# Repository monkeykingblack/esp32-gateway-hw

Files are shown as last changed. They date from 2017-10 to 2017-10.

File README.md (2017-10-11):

#ESP32-GATEWAY-HARDWARE

##Features

- ESP32 WIFI, Bluetooth LE, SoC - 240MHz - Module ESP32 Wrover
- Tracking location by GPS-NEO-6M IC
- Send SMS via sim card by 
- Automatic select 3 power sources (DC6-28V, USB and Battery)
- Charger battery lithium 3.7V
- 1 Power LED, 1 Status GPS LED, 1 Status GSM LED

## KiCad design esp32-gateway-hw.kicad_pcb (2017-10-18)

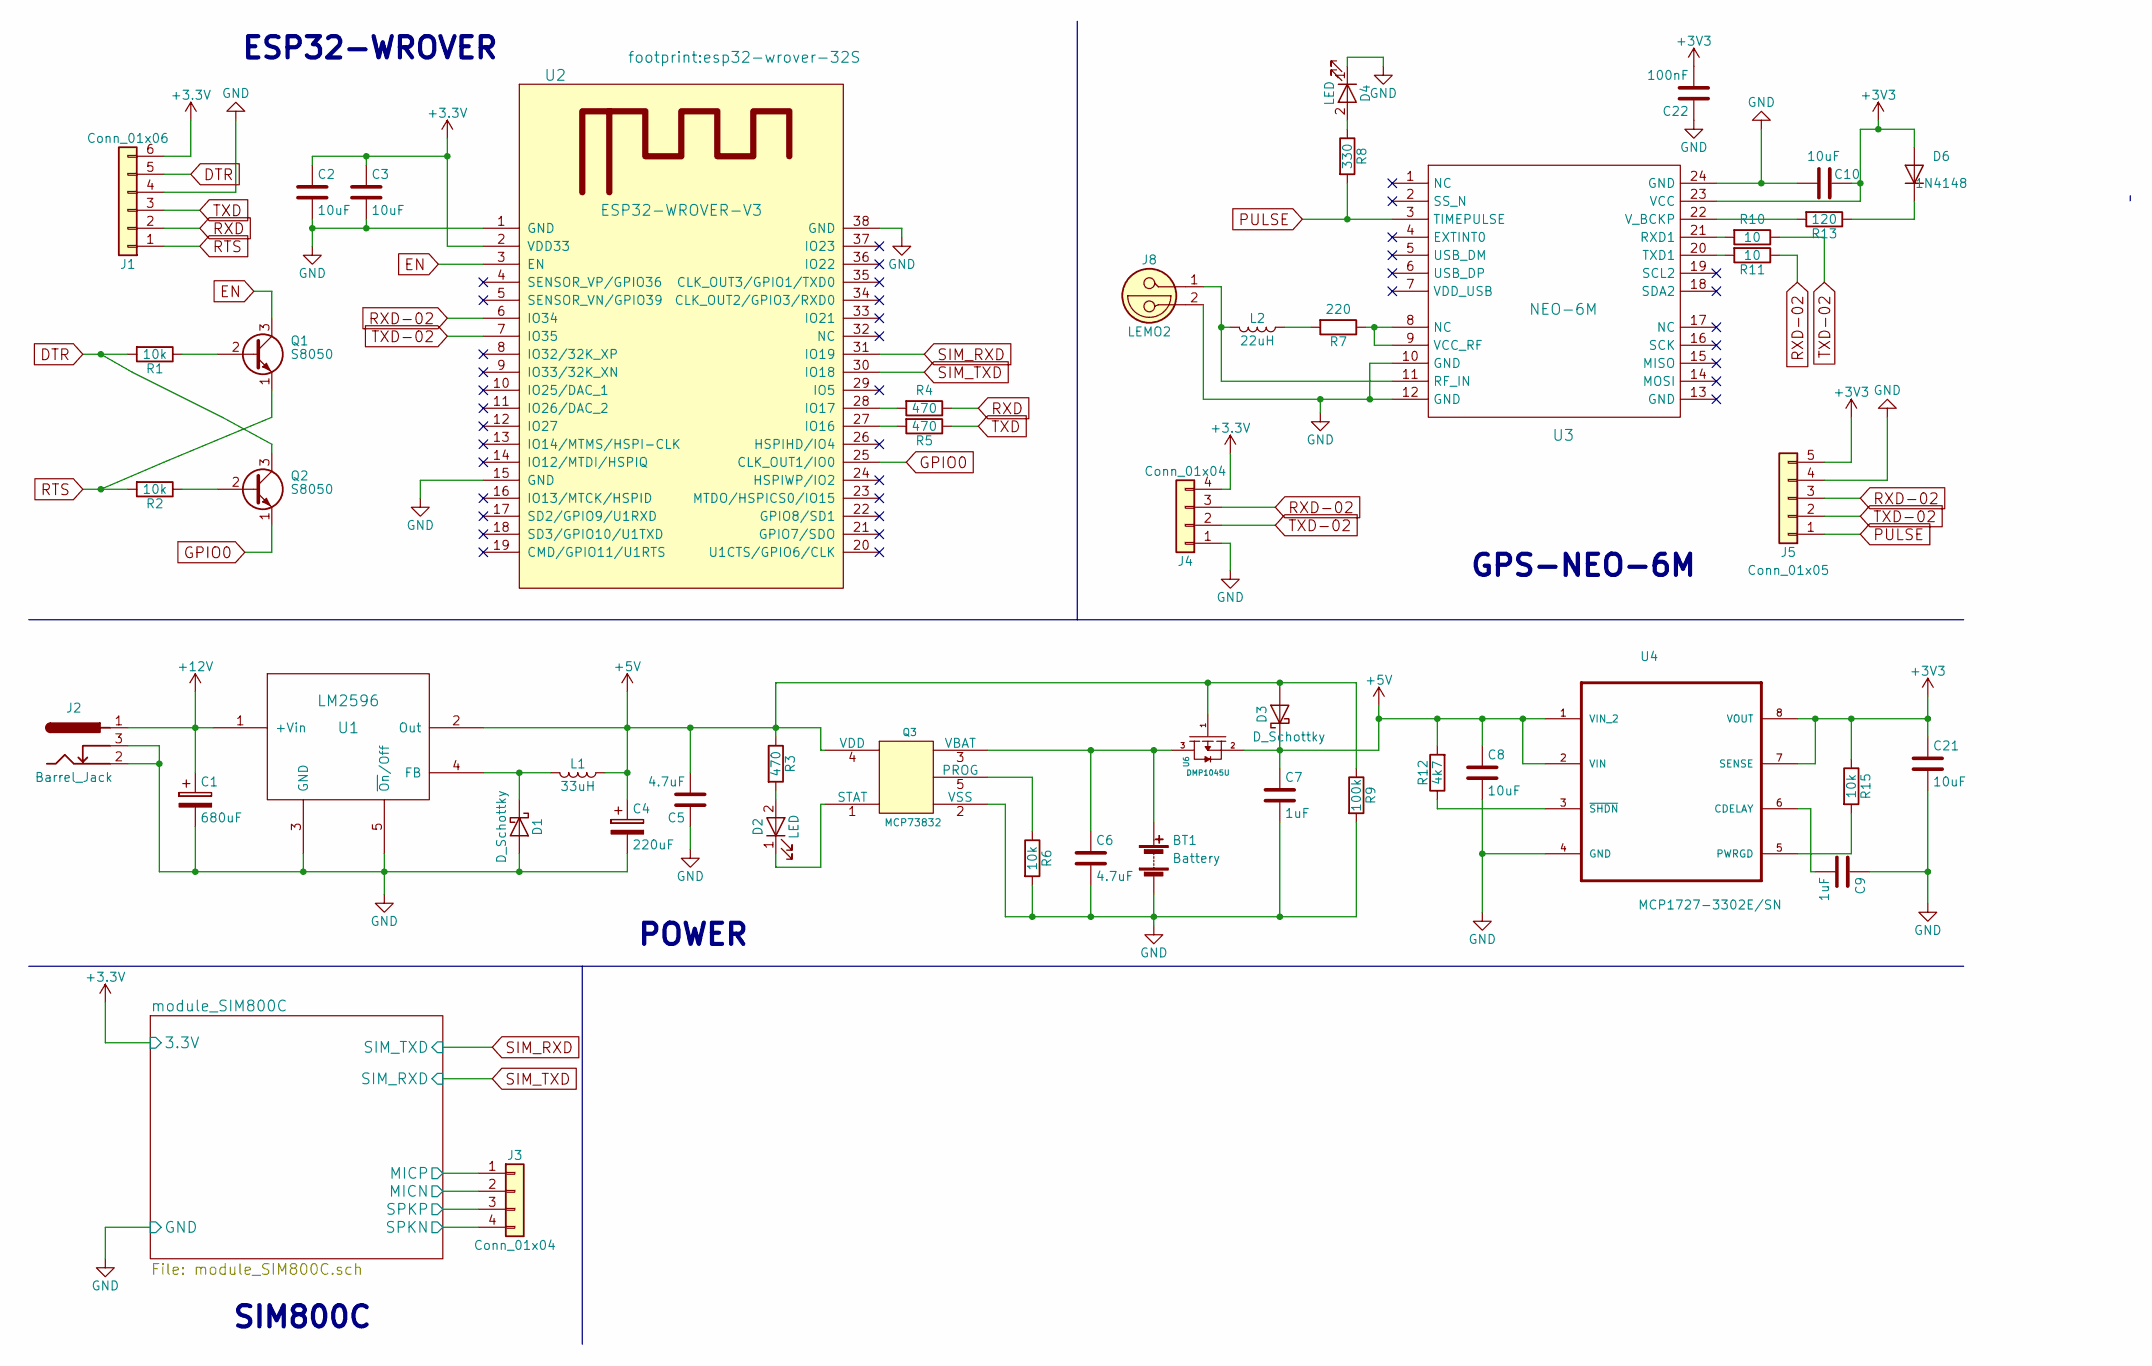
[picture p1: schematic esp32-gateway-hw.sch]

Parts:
BT1: Battery; JST_EH_B02B-EH-A_02x2.50mm_Straight
C1: 680uF; CP_Elec_4x5.3
C2, C3, C8, C10, C21: 10uF; C_0603
C4: 220uF; CP_Elec_4x5.3
C5, C6: 4.7uF; C_0603
C7, C9: 1uF; C_0603
C22: 100nF; C_0603
D1, D3: D_Schottky; D_SOD-123
D2, D4: LED; LED_D3.0mm
D6: 1N4148; D_SOD-123
J1: Conn_01x06; Socket_Strip_Straight_1x06_Pitch2.54mm
J2: Barrel_Jack; CUI-PJ-102A_dc-barrel-jack
J3, J4: Conn_01x04; Socket_Strip_Straight_1x04_Pitch2.54mm
J5: Conn_01x05; Socket_Strip_Straight_1x05_Pitch2.54mm
J8: LEMO2; SMA_Straight
L1: 33uH; INDUCTOR_SMD_DIP2
L2: 22uH; INDUCTOR_SMD_DIP2
Q1, Q2: S8050; SOT-23_standar
Q3: MCP73832; SOT-23-5_HandSoldering
R1, R2, R6, R15: 10k; R_0603
R3, R4, R5: 470; R_0603
R7: 220; R_0603
R8: 330; R_0603
R9: 100k; R_0603
R10, R11: 10; R_0603
R12: 4k7; R_0603
R13: 120; R_0603
U1: LM2596; TO-263-5_TabPin3
U2: ESP32-WROVER-V3; esp32-wrover-32S
U3: NEO-6M; GPS24P-SMD-1.1-16X12.2MM
U4: MCP1727-3302E/SN; SOIC-8_3.9x4.9mm_Pitch1.27mm; Digi-Key_Part_Number MCP1727-3302E/SN-ND
U6: DMP1045U; SOT-23

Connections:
+3V3: C2.1, C3.1, C10.1, C21.1, C22.2, D6.2 (A), J1.6, J4.4, J5.5, R15.1, U2.2 (VDD33), U3.23 (VCC), U4.7 (SENSE), U4.8 (VOUT); also elsewhere on the board
+5V: C4.1, C5.2, C7.1, C8.1, D3.1 (K), D3.2 (A), L1.1, Q3.4 (VDD), R3.1, R9.1, R12.2, U1.2 (Out), U4.1 (VIN_2), U4.2 (VIN), U6.1, U6.2
+12V: C1.1, J2.1, U1.1 (+Vin)
/module_SIM800C/MICN: J3.2; also elsewhere on the board
/module_SIM800C/MICP: J3.1; also elsewhere on the board
/module_SIM800C/SPKN: J3.4; also elsewhere on the board
/module_SIM800C/SPKP: J3.3; also elsewhere on the board
DTR: J1.5, Q2.3 (C), R1.2
EN: Q1.3 (C), U2.3 (EN)
GND: BT1.2 (-), C1.2, C2.2, C3.2, C4.2, C5.1, C6.2, C7.2, C8.2, C9.1, C10.2, C21.2, C22.1, D1.2 (A), D4.1 (K), J1.4, J2.2, J2.3, J4.1, J5.4, J8.2, Q3.2 (VSS), R6.2, R9.2, U1.3 (GND), U1.5 (~On~/Off), U2.1 (GND), U2.15 (GND), U2.38 (GND), U3.10 (GND), U3.12 (GND), U3.24 (GND), U4.4 (GND); also elsewhere on the board
GPIO0: Q2.1 (E), U2.25 (CLK_OUT1/IO0)
unnamed: BT1.1 (+), C6.1, Q3.3 (VBAT), U6.3
unnamed: C9.2, U4.6 (CDELAY)
unnamed: D1.1 (K), L1.2, U1.4 (FB)
unnamed: D2.1 (K), Q3.1 (STAT)
unnamed: D2.2 (A), R3.2
unnamed: D4.2 (A), R8.1
unnamed: D6.1 (K), R13.1
unnamed: J8.1, L2.2, U3.11 (RF_IN)
unnamed: L2.1, R7.2
unnamed: Q1.2 (B), R1.1
unnamed: Q2.2 (B), R2.1
unnamed: Q3.5 (PROG), R6.1
unnamed: R4.2, U2.28 (IO17)
unnamed: R5.2, U2.27 (IO16)
unnamed: R7.1, U3.8 (NC), U3.9 (VCC_RF)
unnamed: R10.2, U3.21 (RXD1)
unnamed: R11.2, U3.20 (TXD1)
unnamed: R12.1, U4.3 (~SHDN)
unnamed: R13.2, U3.22 (V_BCKP)
unnamed: R15.2, U4.5 (PWRGD)
PULSE: J5.1, R8.2, U3.3 (TIMEPULSE)
RTS: J1.1, Q1.1 (E), R2.2
RXD: J1.2, R4.1
RXD-02: J4.3, J5.3, R11.1, U2.6 (IO34)
SIM_RXD: U2.31 (IO19); also elsewhere on the board
SIM_TXD: U2.30 (IO18); also elsewhere on the board
TXD: J1.3, R5.1
TXD-02: J4.2, J5.2, R10.1, U2.7 (IO35)

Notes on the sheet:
ESP32-WROVER
GPS-NEO-6M
POWER
SIM800C

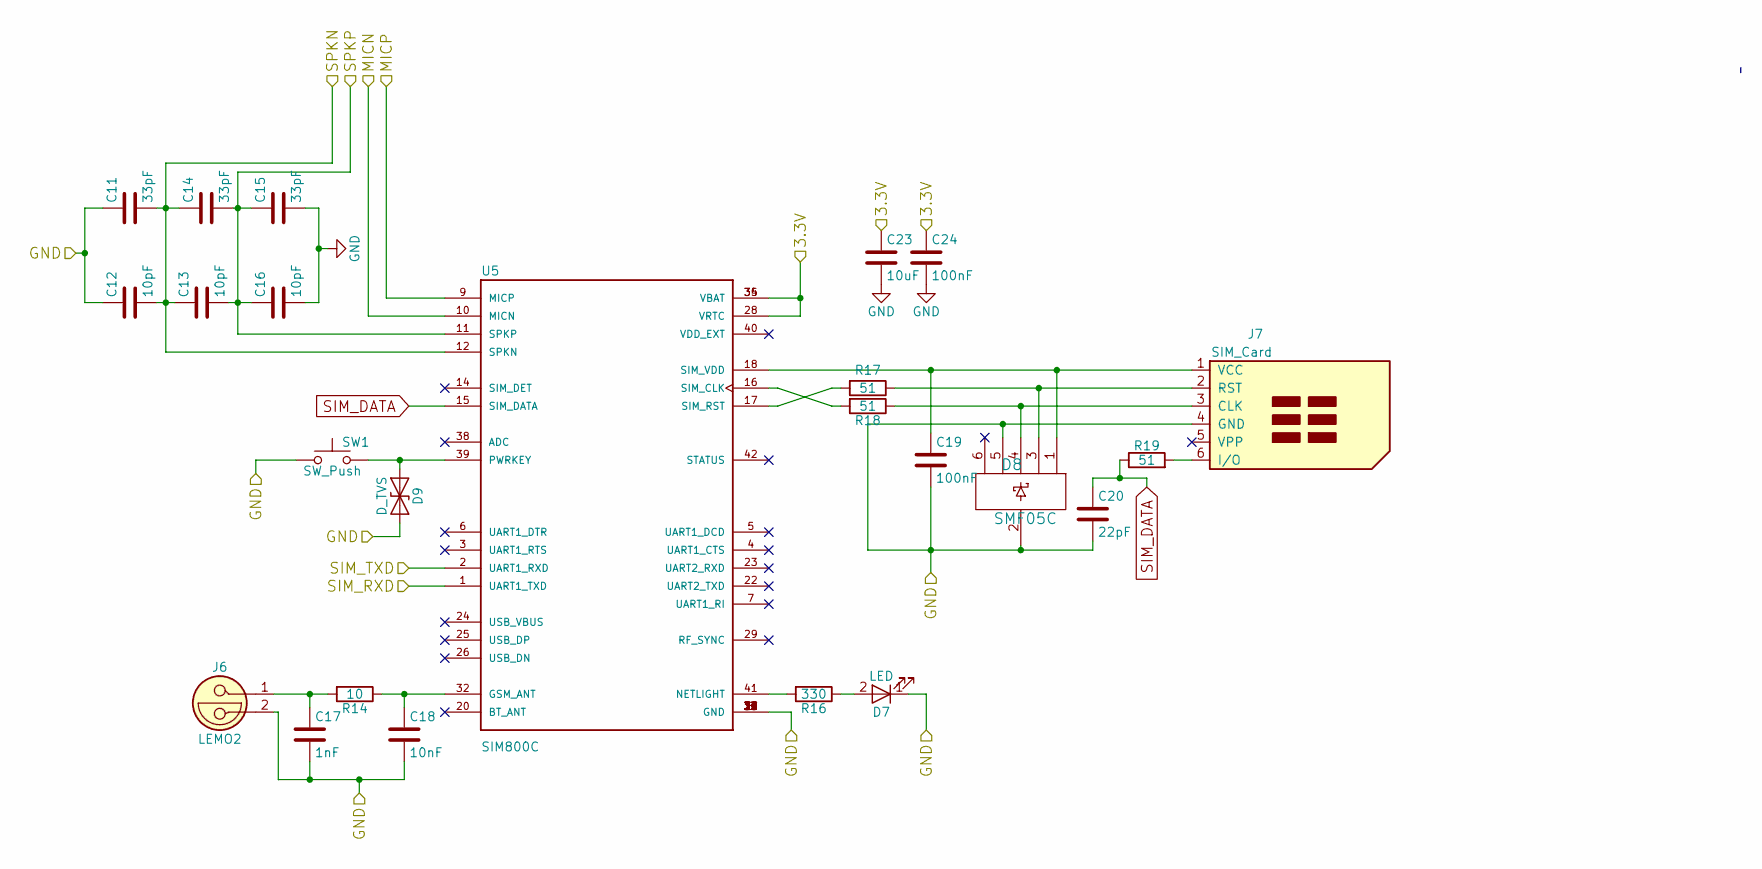
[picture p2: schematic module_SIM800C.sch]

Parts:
C11, C14, C15: 33pF; C_0603
C12, C13, C16: 10pF; C_0603
C17: 1nF; C_0603
C18: 10nF; C_0603
C19, C24: 100nF; C_0603
C20: 22pF; C_0603
C23: 10uF; C_0603
D7: LED; LED_D3.0mm
D8: SMF05C; SC70-6L
D9: D_TVS; DO-214AC(SMA)
J6: LEMO2; SMA_Straight
J7: SIM_Card; MOLEX_47553-2001_SIMCARD
R14: 10; R_0603
R16: 330; R_0603
R17, R18, R19: 51; R_0603
SW1: SW_Push; SW_PUSH_6mm_h4.3mm
U5: SIM800C; sim800C

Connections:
+3V3: C23.1, C24.1, U5.28 (VRTC), U5.34 (VBAT), U5.35 (VBAT); also elsewhere on the board
/module_SIM800C/MICN: U5.10 (MICN); also elsewhere on the board
/module_SIM800C/MICP: U5.9 (MICP); also elsewhere on the board
/module_SIM800C/SPKN: C11.2, C12.2, C13.1, C14.1, U5.12 (SPKN); also elsewhere on the board
/module_SIM800C/SPKP: C13.2, C14.2, C15.1, C16.1, U5.11 (SPKP); also elsewhere on the board
GND: C11.1, C12.1, C15.2, C16.2, C17.2, C18.2, C19.2, C20.2, C23.2, C24.2, D7.1 (K), D8.2, D8.5, D9.2 (A2), J6.2, J7.4 (GND), SW1.1, U5.8 (GND), U5.13 (GND), U5.19 (GND), U5.21 (GND), U5.27 (GND), U5.30 (GND), U5.31 (GND), U5.33 (GND), U5.36 (GND), U5.37 (GND); also elsewhere on the board
unnamed: C17.1, J6.1, R14.2
unnamed: C18.1, R14.1, U5.32 (GSM_ANT)
unnamed: C19.1, D8.1, J7.1 (VCC), U5.18 (SIM_VDD)
unnamed: D7.2 (A), R16.1
unnamed: D8.3, J7.2 (RST), R17.1
unnamed: D8.4, J7.3 (CLK), R18.1
unnamed: D9.1 (A1), SW1.2, U5.39 (PWRKEY)
unnamed: J7.6 (I/O), R19.2
unnamed: R16.2, U5.41 (NETLIGHT)
unnamed: R17.2, U5.17 (SIM_RST)
unnamed: R18.2, U5.16 (SIM_CLK)
SIM_DATA: C20.1, R19.1, U5.15 (SIM_DATA)
SIM_RXD: U5.2 (UART1_RXD); also elsewhere on the board
SIM_TXD: U5.1 (UART1_TXD); also elsewhere on the board

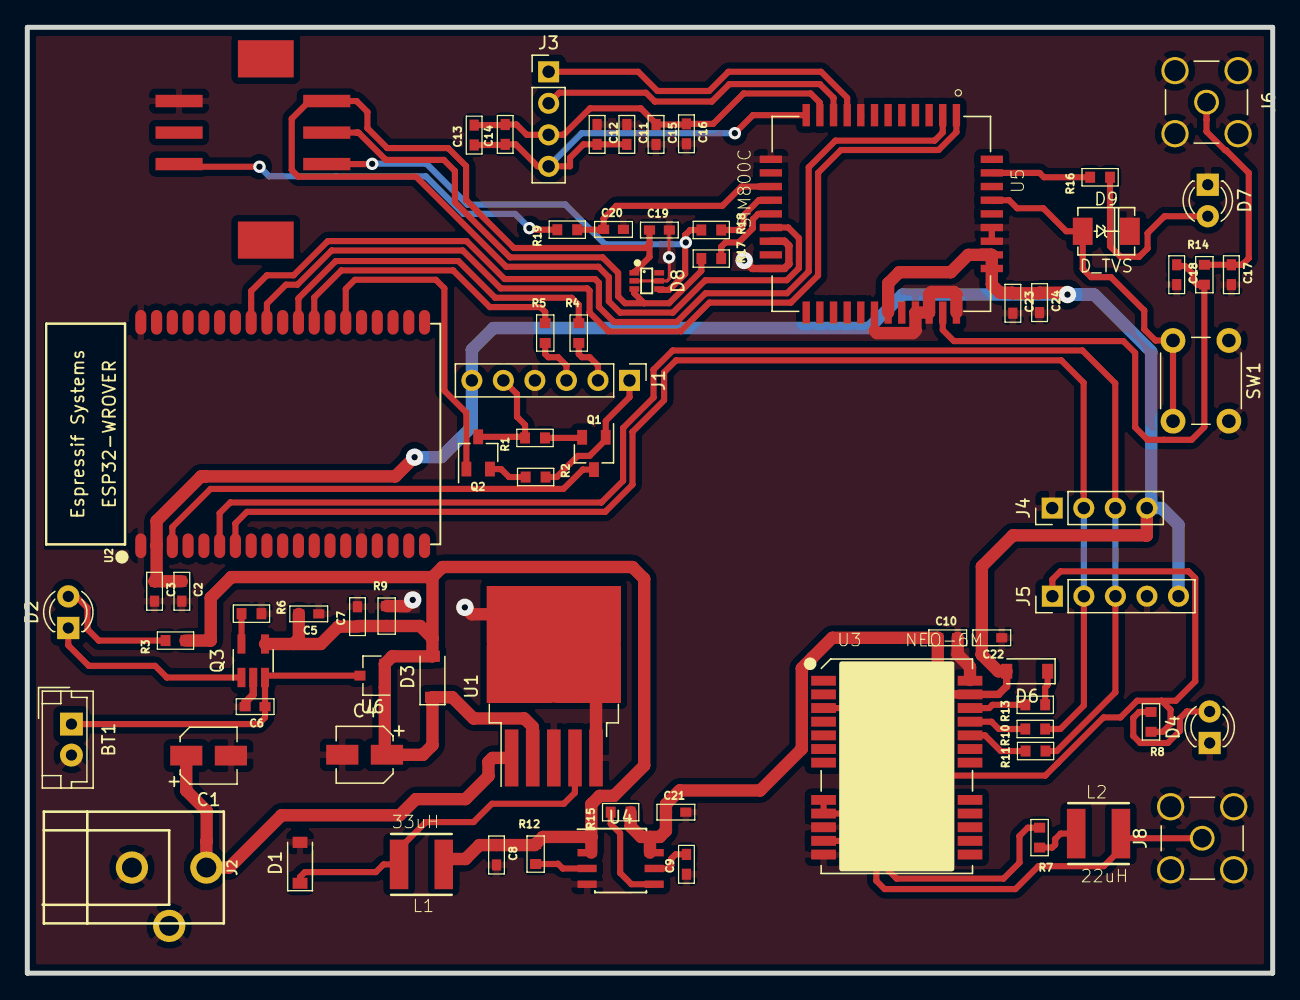
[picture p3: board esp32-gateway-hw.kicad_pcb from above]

Board: 2 copper layers, 100.3 x 76.2 mm, 72 parts (0 on the bottom side), 51 nets.

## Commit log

2017-10-11 Schematic and footprint all component
    [esp32-gateway-hw.kicad_pcb, esp32-gateway-hw.sch, module_SIM800C.sch]
2017-10-11 fixed untracked files
    [esp32-gateway-hw.sch, module_SIM800C.sch]
2017-10-11 fix SIM_Card pin out
    [module_SIM800C.sch]
2017-10-11 Change C1, C4 to polarized capacitors
    [esp32-gateway-hw.sch]
2017-10-11 Add button to pin PWRKEY in SIM800C for handle power on SIM800C
    [module_SIM800C.sch]
2017-10-11 fix UART interface module GPS
    [esp32-gateway-hw.sch]
2017-10-11 Make PCB
    [esp32-gateway-hw.kicad_pcb, esp32-gateway-hw.sch, module_SIM800C.sch]
2017-10-17 Change TC1264 to MCP1727
    [esp32-gateway-hw.sch, module_SIM800C.sch]
2017-10-17 replace mosfet in Power Module
    [esp32-gateway-hw.sch]
2017-10-17 add PCB
    [esp32-gateway-hw.kicad_pcb, module_SIM800C.sch]
2017-10-17 add keepout area on anthena of esp32-wrover
    [esp32-gateway-hw.kicad_pcb]
2017-10-18 redraw PCB
    [esp32-gateway-hw.kicad_pcb]
2017-10-18 add 3D shape
    [esp32-gateway-hw.kicad_pcb, esp32-gateway-hw.sch]
2017-10-18 add RF connector 3D shape
    [esp32-gateway-hw.kicad_pcb]
